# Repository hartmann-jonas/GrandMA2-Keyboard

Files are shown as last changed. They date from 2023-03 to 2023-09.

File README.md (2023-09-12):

# GrandMA2-Keyboard
Custom handwired keyboard of the grandMA2 programming section, that sends MIDI notes to control the console.

[](https://user-images.githubusercontent.com/80170229/210251196-0c96b4aa-1008-4bc5-b2f8-234fe1ce431a.jpg)

* Keyboard Maintainer: [Jonas Hartmann](https://github.com/hartmann-jonas)
* Used controller: Raspberry Pi Pico
* Used switches: Cherry MX Black

## Parts:
Electronics
|Amount |Part |Where to buy |
|---|---|---|
|70 |Cherry MX Black (For the same feeling as on the console) |[Reichelt.de](https://www.reichelt.de/de/en/cherry-mx-black-button-module-snap-on-attachment-cherry-mx1a-11nn-p202566.html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) (Germany)|
|70 |Diodes 1N 914 |[Reichelt.de](https://www.reichelt.de/de/en/rectifier-diode-do35-100-v-0-2-a-1n-914-p1763.html?nbc=1&&r=1) (Germany)|
|1 |Raspberry Pi Pico |[Reichelt.de](https://www.reichelt.de/de/en/raspberry-pi-pico-rp2040-cortex-m0-microusb-header-rasp-pi-pico-h-p305824.html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) (Germany)|
|1 |Insulated copper wire |[Reichelt.de](https://www.reichelt.de/de/en/insulated-braided-copper-wire-10-m-1-x-0-14-mm-red-litze-rt-p10297.html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) (Germany)|

Lasercut parts
|Amount |Part |File |
|---|---|---|
|1 |Top Plate |[top-plate.dxf](https://github.com/hartmann-jonas/GrandMA2-Keyboard/blob/main/dxf-files/top-plate.dxf) |
|1 |Switch Plate |[switch-plate.dxf](https://github.com/hartmann-jonas/GrandMA2-Keyboard/blob/main/dxf-files/switch-plate.dxf) |
|1 |Bottom Plate |[bottom-plate.dxf](https://github.com/hartmann-jonas/GrandMA2-Keyboard/blob/main/dxf-files/bottom-plate.dxf) |
|1 |Cable Plate  |[cable-plate.dxf](https://github.com/hartmann-jonas/GrandMA2-Keyboard/blob/main/dxf-files/cable-plate.dxf) |
|5 |Wall Plate |[wall-plate.dxf](https://github.com/hartmann-jonas/GrandMA2-Keyboard/blob/main/dxf-files/wall-plate.dxf) |

## Guide:
*All the parts as well as the plates are required*

### Step 1:
Place all the switches in the switch plate

### Step 2:
Solder the switches and diodes, according to the wiring matrix. *Don't solder the rows and columns to the pico yet!*

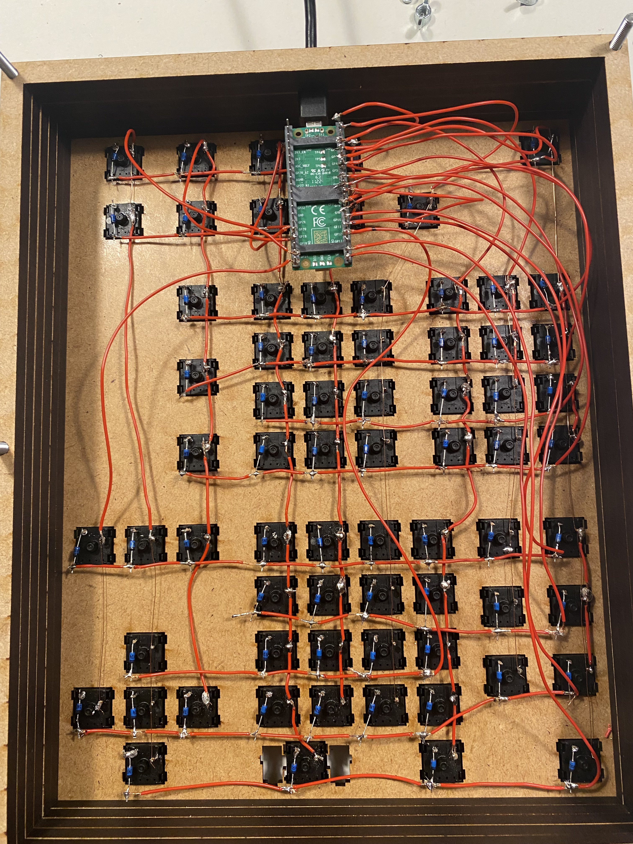
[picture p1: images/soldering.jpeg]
[](https://raw.githubusercontent.com/hartmann-jonas/GrandMA2-Keyboard/main/images/soldering.jpeg)

Do not go too hot with the temperature on the soldering iron. 300°C worked fine for me.

### Step 3:
* You need to install KMK on the microcontroller by following [this](https://github.com/KMKfw/kmk_firmware/blob/master/docs/en/Getting_Started.md) guide.
* After installing KMK you need to replace the contents of your code.py or main.py file with [this file](https://github.com/hartmann-jonas/GrandMA2-Keyboard/blob/main/code.py).

* If you run into errors when trying to send MIDI notes you might need to install the [adafruit_midi](http://kmkfw.io/docs/midi/) library on the microcontroller.

### Step 4:
Now solder the rows and columns to the pico
|Row |Pico |Column |Pico |
|---|-----|---|-----|
|Row 0  |GP 5 |Column 0 |GP 4 |
|Row 1  |GP 8 |Column 1 |GP 3 |
|Row 2  |GP 6 |Column 2 |GP 2 |
|Row 3  |GP 7 |Column 3 |GP 1 |
|Row 4  |GP 9 |Column 4 |GP 0 |
|Row 5  |GP 10|Column 5 |GP 19|
|Row 6  |GP 11|Column 6 |GP 18|
|Row 7  |GP 12|Column 7 |GP 17|
|Row 8  |GP 13|Column 8 |GP 16|
|Row 9  |GP 14|
|Row 10 |GP 15|

### Step 5:
* Select the keyboard in the GrandMA2 onPC's *Midi In* settings
* Map the midi notes to the midi remote in GrandMA2 onPC

### Wiring Matrix:
keyboard
[keyboard.pdf](https://github.com/hartmann-jonas/GrandMA2-Keyboard/files/10332369/keyboard.pdf)

### Firmware:
The firmware is written using [KMK](http://kmkfw.io).

### Midi:
The midi notes need to be mapped new in every different showfile!

To import the midi mappings into your showfile, copy the [MA2_Keyboard.xml](https://github.com/hartmann-jonas/GrandMA2-Keyboard/blob/main/midi-mapping/MA2_Keyboard.xml) into your `importexport` folder of your GrandMA2 install and run the import command
```
import "MA2_Keyboard" at remote 2
```
***NOTE***: If you already have midi mapping setup in your showfile, make sure there are no collisions of midi note numbers.

## Setup in GrandMA2 onPC
You need to set the "Note" value in GrandMA2's Remote Input Setting to the following table

|Midi Number|Key|
|--|---|
|0|Encoder Key |
|1|Tools |
|2|Setup |
|3|Backup |
|4|Help |
|5|Blind |
|6|Freeze |
|7|Preview |
|8|Assign |
|9|Align |
|10|Fix |
|11|Select |
|12|Off |
|13|View |
|14|Effect |
|15|Goto |
|16|Del |
|17|Temp |
|18|Top |
|19|On |
|20|Page |
|21|Macro |
|22|Preset |
|23|Copy |
|24|<<< |
|25|Learn |
|26|>>> |
|27|Sequ |
|28|Cue |
|29|Exec |
|30|Go - |
|31|Pause |
|32|Go + |
|33|Channel |
|34|Fixture |
|35|Group |
|36|Move |
|37|Time |
|38|Esc |
|39|7 |
|40|8 |
|41|9 |
|42|+ |
|43|Full |
|44|Highlight  |
|45|Solo |
|46|Edit |
|47|Oops |
|48|4 |
|49|5 |
|50|6 |
|51|Thru |
|52|1 |
|53|2 |
|54|3 |
|55|- |
|56|Up |
|57|Update |
|58|Clear |
|59|0 |
|60|. (Dot) |
|61|If |
|62|At |
|63|Previous |
|64|Set |
|65|Next |
|66|Store |
|67|MA |
|68|Please |
|69|Down |

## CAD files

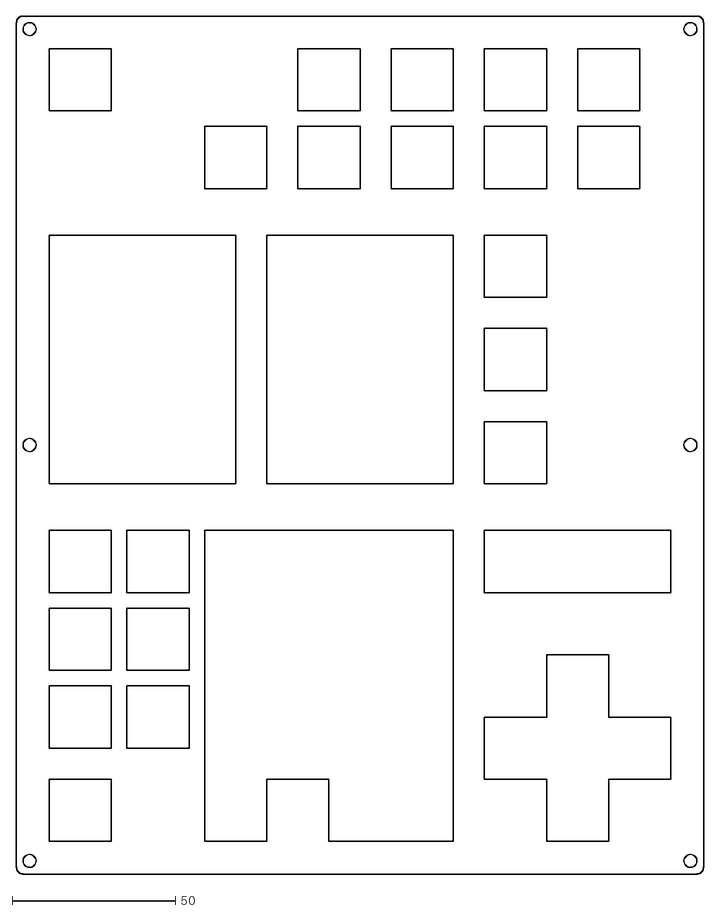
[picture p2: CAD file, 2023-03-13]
dxf-files/top-plate.dxf
210.5 x 262.9

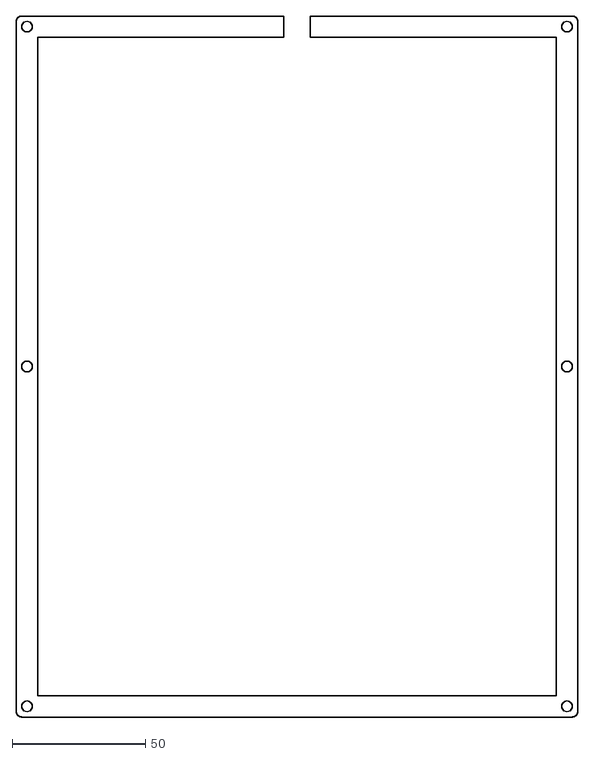
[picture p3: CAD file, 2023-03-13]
dxf-files/cable-plate.dxf
210.5 x 262.9

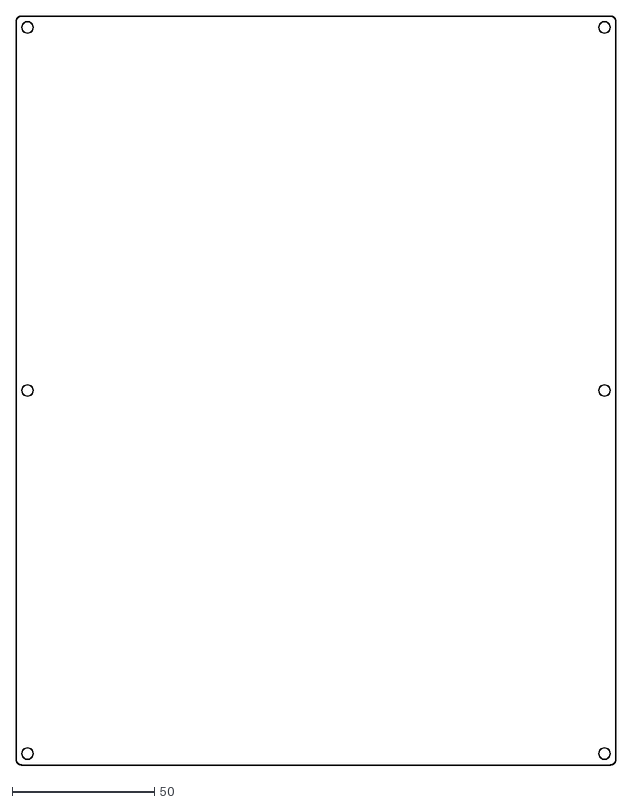
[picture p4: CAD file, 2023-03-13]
dxf-files/bottom-plate.dxf
210.5 x 262.9

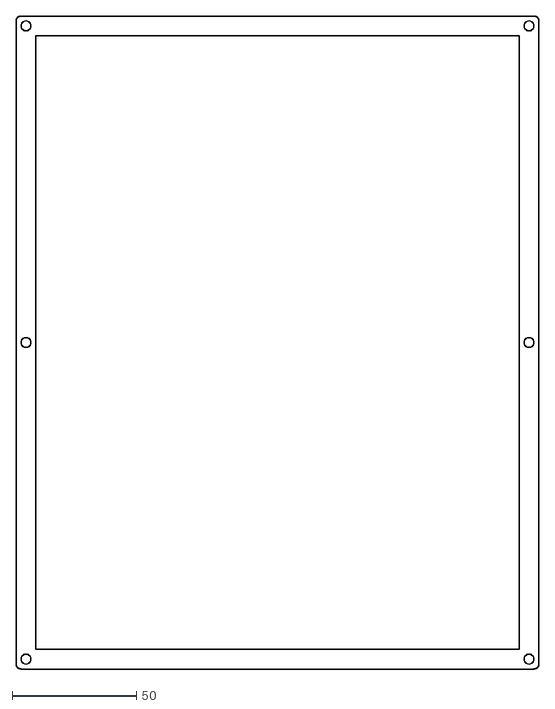
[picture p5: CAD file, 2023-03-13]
dxf-files/wall-plate.dxf
210.5 x 262.9

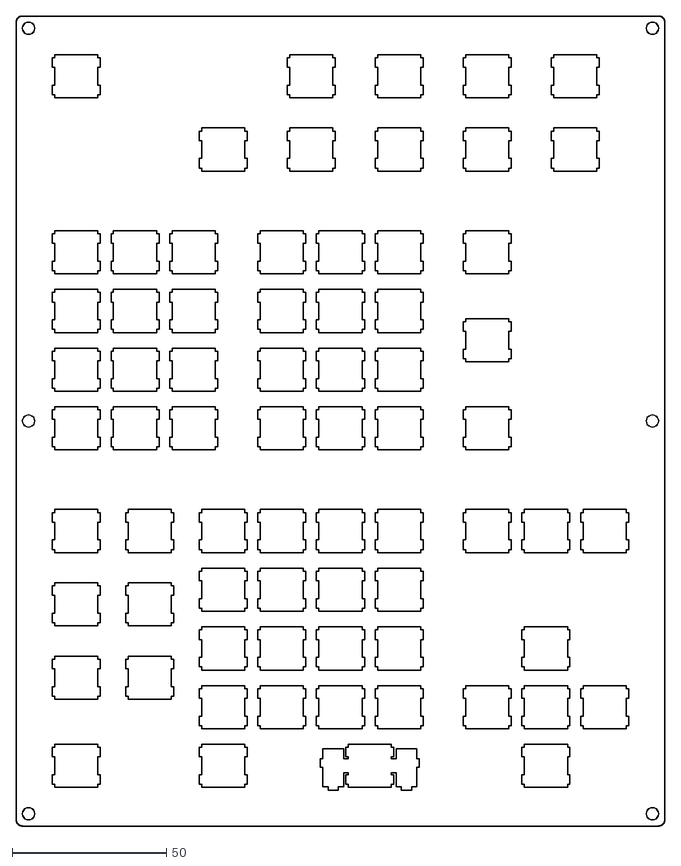
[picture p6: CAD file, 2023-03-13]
dxf-files/switch-plate.dxf
210.5 x 262.9

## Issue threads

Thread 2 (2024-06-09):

Keycaps

joa77, 2024-06-09:
Nice project!

Can you explain where to geht the keycaps for the cherry switches?

hartmann-jonas, 2024-07-02:
I currently don't habe any switches for the keyboard, but there are keycaps where you can insert paper labels.
Something like [this](https://keycaps-vibe.com/products/relegendable-keycaps).

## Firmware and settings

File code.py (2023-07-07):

print("Starting")

import board

from kmk.kmk_keyboard import KMKKeyboard
from kmk.keys import KC
from kmk.scanners import DiodeOrientation

keyboard = KMKKeyboard()

from kmk.modules.midi import MidiKeys
keyboard.modules.append(MidiKeys())


keyboard.col_pins = (board.GP4, board.GP3, board.GP2, board.GP1, board.GP0, board.GP19, board.GP18, board.GP17, board.GP16)
keyboard.row_pins = (board.GP5, board.GP8, board.GP6, board.GP7, board.GP9, board.GP10, board.GP11, board.GP12, board.GP13, board.GP14, board.GP15)
keyboard.diode_orientation = DiodeOrientation.COL2ROW

# Empty keys
XXXXXXXXXX = KC.NO

keyboard.keymap = [
    [
        KC.MIDI_NOTE(0, 100),   XXXXXXXXXX,             XXXXXXXXXX,             XXXXXXXXXX,             KC.MIDI_NOTE(1, 100),   KC.MIDI_NOTE(2, 100),   KC.MIDI_NOTE(3, 100),   KC.MIDI_NOTE(4, 100),   XXXXXXXXXX,\
        XXXXXXXXXX,             XXXXXXXXXX,             XXXXXXXXXX,             KC.MIDI_NOTE(5, 100),   KC.MIDI_NOTE(6, 100),   KC.MIDI_NOTE(7, 100),   KC.MIDI_NOTE(8, 100),   KC.MIDI_NOTE(9, 100),   XXXXXXXXXX,\
        KC.MIDI_NOTE(10, 100),  KC.MIDI_NOTE(11, 100),  KC.MIDI_NOTE(12, 100),  KC.MIDI_NOTE(13, 100),  KC.MIDI_NOTE(14, 100),  KC.MIDI_NOTE(15, 100),  KC.MIDI_NOTE(16, 100),  XXXXXXXXXX,             XXXXXXXXXX,\
        KC.MIDI_NOTE(17, 100),  KC.MIDI_NOTE(18, 100),  KC.MIDI_NOTE(19, 100),  KC.MIDI_NOTE(20, 100),  KC.MIDI_NOTE(21, 100),  KC.MIDI_NOTE(22, 100),  KC.MIDI_NOTE(23, 100),  XXXXXXXXXX,             XXXXXXXXXX,\
        KC.MIDI_NOTE(24, 100),  KC.MIDI_NOTE(25, 100),  KC.MIDI_NOTE(26, 100),  KC.MIDI_NOTE(27, 100),  KC.MIDI_NOTE(28, 100),  KC.MIDI_NOTE(29, 100),  XXXXXXXXXX,             XXXXXXXXXX,             XXXXXXXXXX,\
        KC.MIDI_NOTE(30, 100),  KC.MIDI_NOTE(31, 100),  KC.MIDI_NOTE(32, 100),  KC.MIDI_NOTE(33, 100),  KC.MIDI_NOTE(34, 100),  KC.MIDI_NOTE(35, 100),  KC.MIDI_NOTE(36, 100),  XXXXXXXXXX,             XXXXXXXXXX,\
        KC.MIDI_NOTE(37, 100),  KC.MIDI_NOTE(38, 100),  KC.MIDI_NOTE(39, 100),  KC.MIDI_NOTE(40, 100),  KC.MIDI_NOTE(41, 100),  KC.MIDI_NOTE(42, 100),  KC.MIDI_NOTE(43, 100),  KC.MIDI_NOTE(44, 100),  KC.MIDI_NOTE(45, 100),\
        KC.MIDI_NOTE(46, 100),  KC.MIDI_NOTE(47, 100),  KC.MIDI_NOTE(48, 100),  KC.MIDI_NOTE(49, 100),  KC.MIDI_NOTE(50, 100),  KC.MIDI_NOTE(51, 100),  XXXXXXXXXX,             XXXXXXXXXX,             XXXXXXXXXX,\
        XXXXXXXXXX,             XXXXXXXXXX,             KC.MIDI_NOTE(52, 100),  KC.MIDI_NOTE(53, 100),  KC.MIDI_NOTE(54, 100),  KC.MIDI_NOTE(55, 100),  XXXXXXXXXX,             KC.MIDI_NOTE(56, 100),  XXXXXXXXXX,\
        KC.MIDI_NOTE(57, 100),  KC.MIDI_NOTE(58, 100),  KC.MIDI_NOTE(59, 100),  KC.MIDI_NOTE(60, 100),  KC.MIDI_NOTE(61, 100),  KC.MIDI_NOTE(62, 100),  KC.MIDI_NOTE(63, 100),  KC.MIDI_NOTE(64, 100),  KC.MIDI_NOTE(65, 100),\
        KC.MIDI_NOTE(66, 100),  XXXXXXXXXX,             KC.MIDI_NOTE(67, 100),  XXXXXXXXXX,             XXXXXXXXXX,             KC.MIDI_NOTE(68, 100),  XXXXXXXXXX,             KC.MIDI_NOTE(69, 100),  XXXXXXXXXX,\
    ]
]

if __name__ == '__main__':
    keyboard.go()
